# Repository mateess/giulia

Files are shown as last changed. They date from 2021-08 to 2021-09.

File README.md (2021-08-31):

# Giulia
### 40% keyboard project

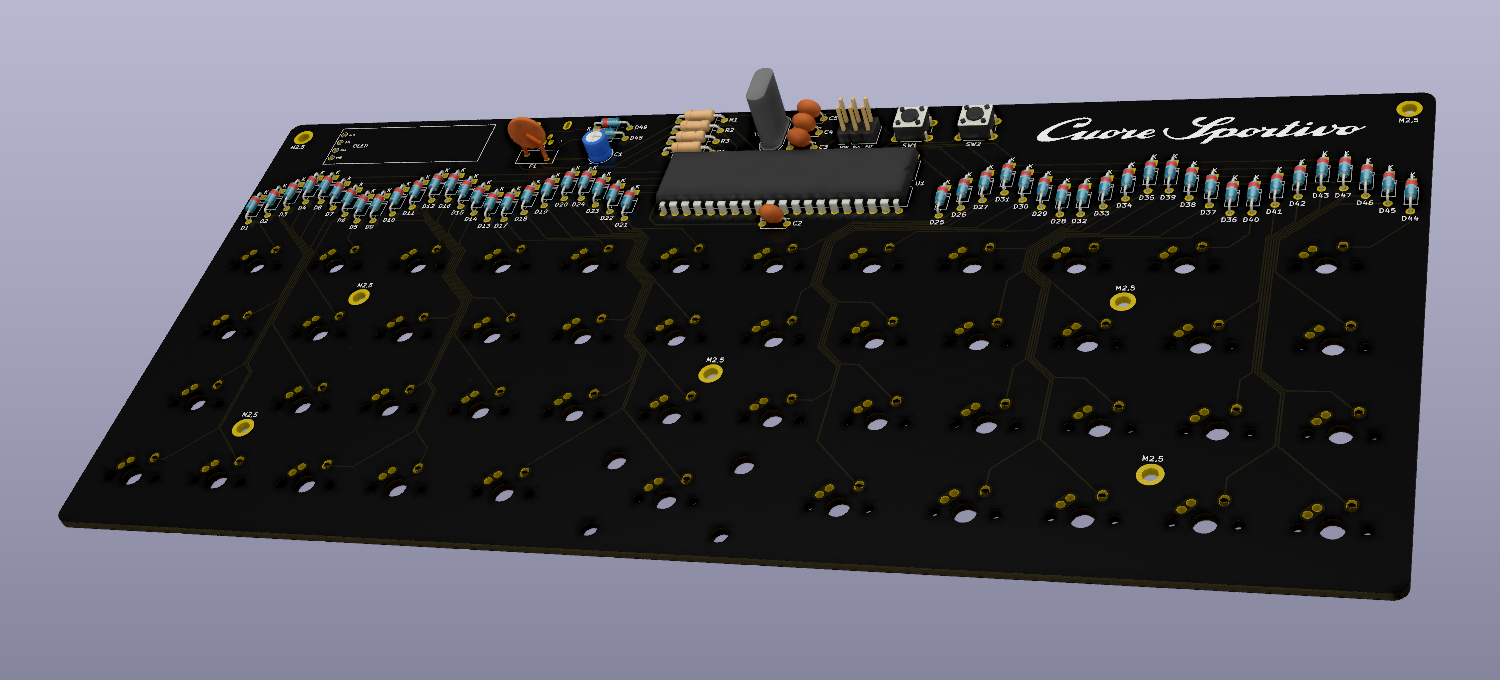
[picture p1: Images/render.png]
render


This will hopefully one day be a complete keyboard.  
Software side is USBaspLoader into QMK  
Inspired by coseyfannitutti's through-hole kits, but with some changes:
- Unistagger layout (like UT47)
- No sandwich, just PCB tray-mounted in a 3D printed lowpro case
- Despite being 40%, uses a "big" ATMega32A controller in DIP
- RGB underglow
- OLED to be admired by non-keeb people and possibly be useful for _stuff_

#### Credit/libraries used:
[Digikey](https://github.com/Digi-Key/digikey-kicad-library) - Molex USB connector  
[foostan](https://github.com/foostan/kbd) - OLED  
[ai03](https://github.com/ai03-2725/MX_Alps_Hybrid) - MX/ALPS switch

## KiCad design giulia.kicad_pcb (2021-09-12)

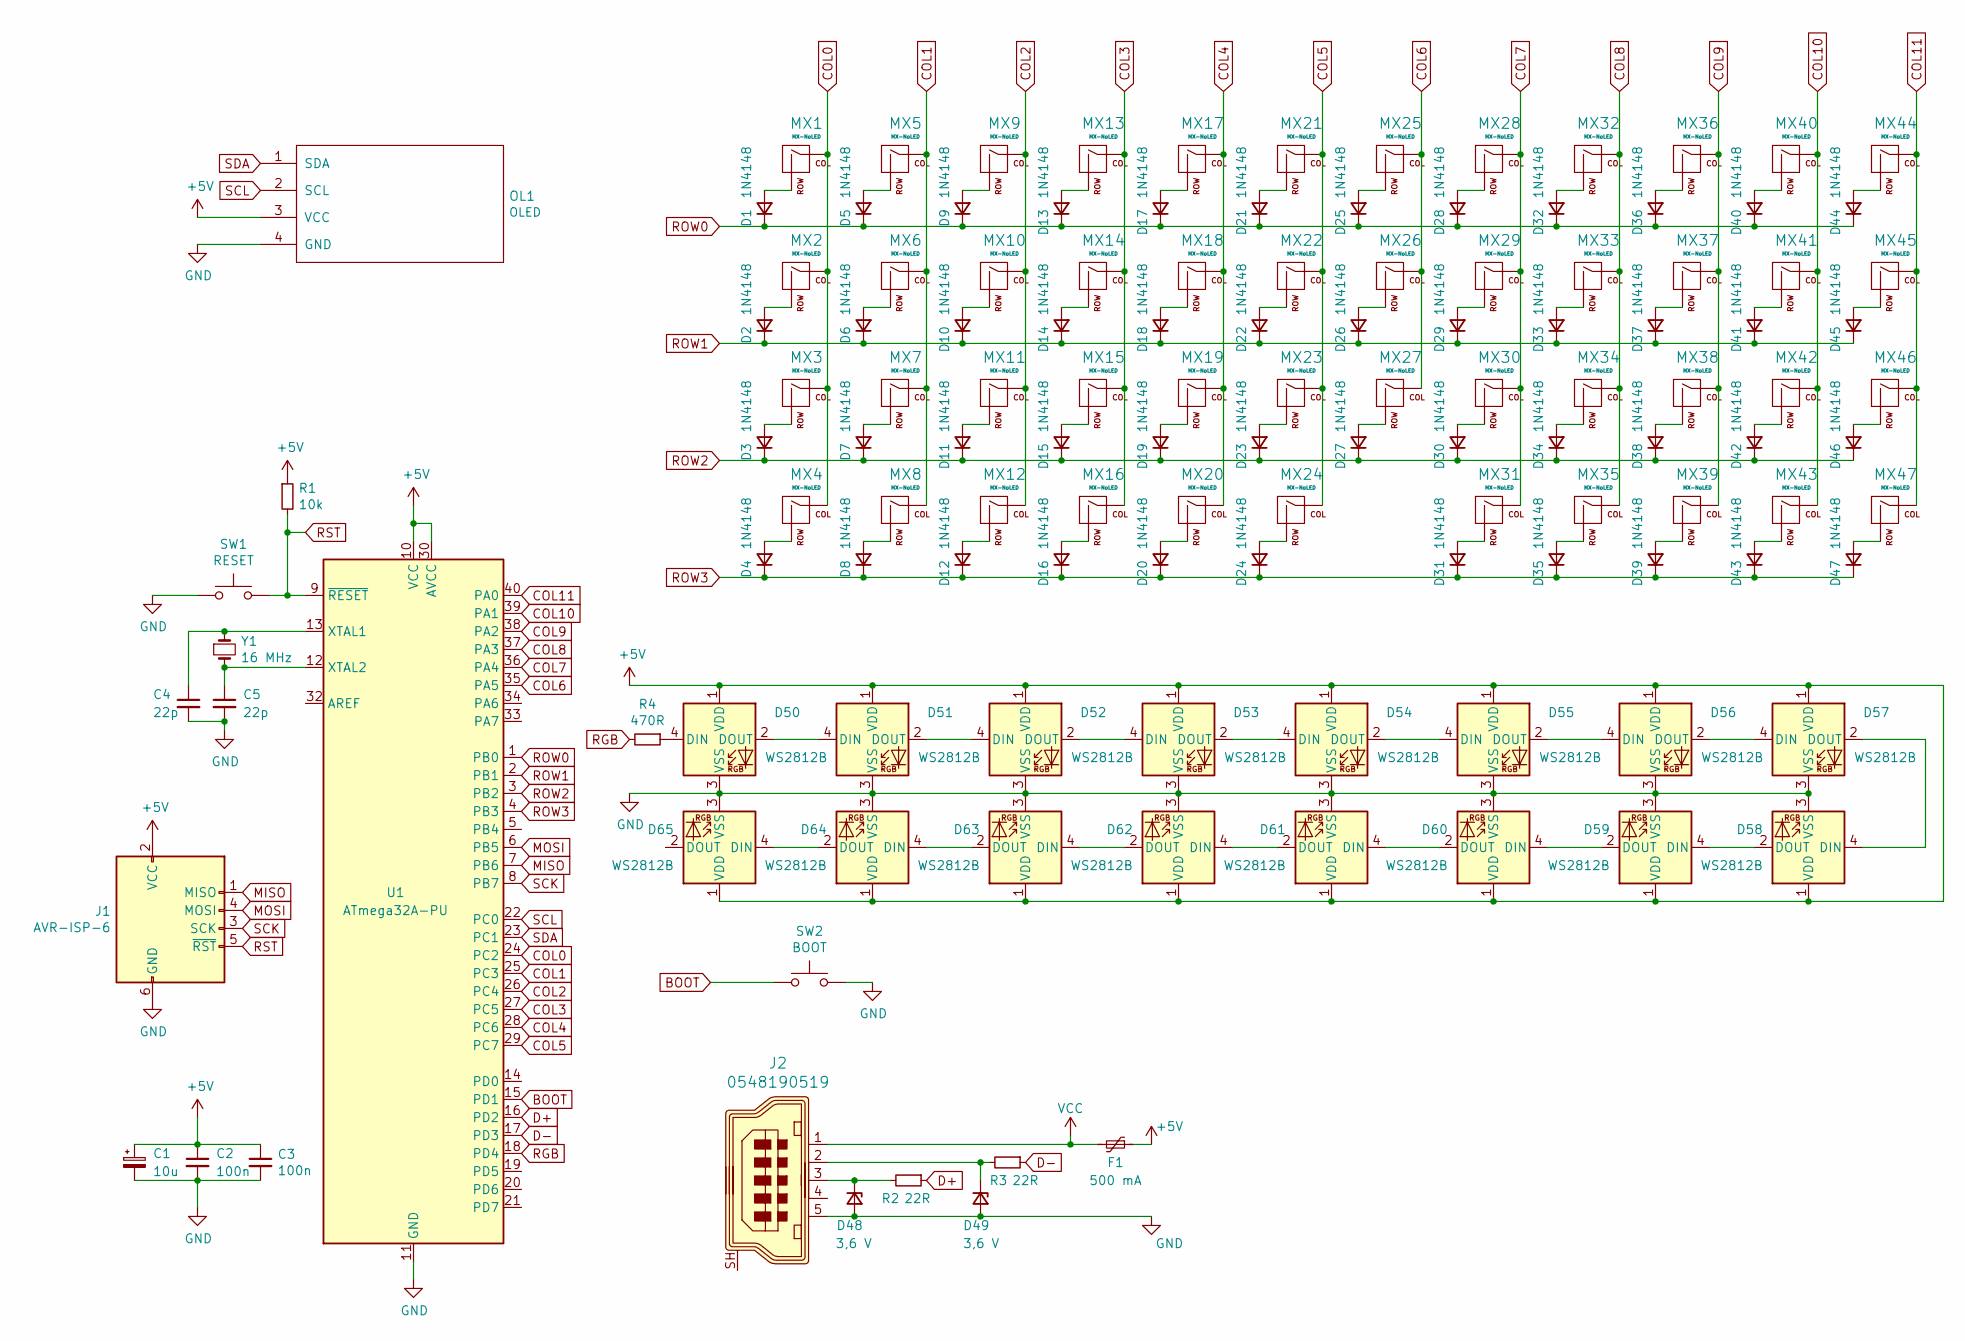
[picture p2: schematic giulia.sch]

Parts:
C1: 10u; CP_Radial_D5.0mm_P2.00mm
C2, C3: 100n; C_Disc_D5.0mm_W2.5mm_P5.00mm
C4, C5: 22p; C_Disc_D5.0mm_W2.5mm_P5.00mm
D1, D2, D3, D4, D5, D6, D7, D8, D9, D10, D11, D12, D13, D14, D15, D16, D17, D18, D19, D20, D21, D22, D23, D24, D25, D26, D27, D28, D29, D30, D31, D32, D33, D34, D35, D36, D37, D38, D39, D40, D41, D42, D43, D44, D45, D46, D47: 1N4148; D_DO-35_SOD27_P7.62mm_Horizontal_Giulia
D48, D49: 3,6 V; D_DO-35_SOD27_P7.62mm_Zener
D50, D51, D52, D53, D54, D55, D56, D57, D58, D59, D60, D61, D62, D63, D64, D65: WS2812B; LED_WS2812B_PLCC4_5.0x5.0mm_P3.2mm
F1: 500 mA; Fuse_BelFuse_0ZRE0005FF_L8.3mm_W3.8mm
J1: AVR-ISP-6; PinHeader_2x03_P2.54mm_Vertical
J2: 0548190519; USB_Mini_B_Female_548190519; MPN 0548190519; Digi-Key_PN WM17115-ND
MX1, MX4, MX5, MX6, MX7, MX8, MX9, MX10, MX11, MX12, MX13, MX14, MX15, MX16, MX17, MX18, MX19, MX21, MX22, MX23, MX25, MX26, MX27, MX28, MX29, MX30, MX32, MX33, MX34, MX35, MX36, MX37, MX38, MX39, MX40, MX41, MX42, MX43, MX46, MX47: MX-NoLED; MX-1U-NoLED
MX2, MX20, MX31, MX45: MX-NoLED; MX-1.25U-NoLED
MX3, MX44: MX-NoLED; MX-1.5U-NoLED
MX24: MX-NoLED; MX-2U-ReversedStabilizers-NoLED
OL1: OLED
R1: 10k; R_Axial_DIN0207_L6.3mm_D2.5mm_P10.16mm_Horizontal
R2, R3: 22R; R_Axial_DIN0207_L6.3mm_D2.5mm_P10.16mm_Horizontal
R4: 470R; R_Axial_DIN0207_L6.3mm_D2.5mm_P10.16mm_Horizontal
SW1: RESET; SW_PUSH_6mm
SW2: BOOT; SW_PUSH_6mm
U1: ATmega32A-PU; DIP-40_W15.24mm
Y1: 16 MHz; Crystal_HC49-U_Vertical

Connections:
+5V: C1.1, C2.1, C3.1, D50.1 (VDD), D51.1 (VDD), D52.1 (VDD), D53.1 (VDD), D54.1 (VDD), D55.1 (VDD), D56.1 (VDD), D57.1 (VDD), D58.1 (VDD), D59.1 (VDD), D60.1 (VDD), D61.1 (VDD), D62.1 (VDD), D63.1 (VDD), D64.1 (VDD), D65.1 (VDD), F1.1, J1.2 (VCC), OL1.3 (VCC), R1.1, U1.10 (VCC), U1.30 (AVCC)
BOOT: SW2.1, U1.15 (PD1)
COL0: MX1.1 (COL), MX2.1 (COL), MX3.1 (COL), MX4.1 (COL), U1.24 (PC2)
COL1: MX5.1 (COL), MX6.1 (COL), MX7.1 (COL), MX8.1 (COL), U1.25 (PC3)
COL2: MX9.1 (COL), MX10.1 (COL), MX11.1 (COL), MX12.1 (COL), U1.26 (PC4)
COL3: MX13.1 (COL), MX14.1 (COL), MX15.1 (COL), MX16.1 (COL), U1.27 (PC5)
COL4: MX17.1 (COL), MX18.1 (COL), MX19.1 (COL), MX20.1 (COL), U1.28 (PC6)
COL5: MX21.1 (COL), MX22.1 (COL), MX23.1 (COL), MX24.1 (COL), U1.29 (PC7)
COL6: MX25.1 (COL), MX26.1 (COL), MX27.1 (COL), U1.35 (PA5)
COL7: MX28.1 (COL), MX29.1 (COL), MX30.1 (COL), MX31.1 (COL), U1.36 (PA4)
COL8: MX32.1 (COL), MX33.1 (COL), MX34.1 (COL), MX35.1 (COL), U1.37 (PA3)
COL9: MX36.1 (COL), MX37.1 (COL), MX38.1 (COL), MX39.1 (COL), U1.38 (PA2)
COL10: MX40.1 (COL), MX41.1 (COL), MX42.1 (COL), MX43.1 (COL), U1.39 (PA1)
COL11: MX44.1 (COL), MX45.1 (COL), MX46.1 (COL), MX47.1 (COL), U1.40 (PA0)
D+: R2.1, U1.16 (PD2)
D-: R3.1, U1.17 (PD3)
GND: C1.2, C2.2, C3.2, C4.2, C5.2, D48.2 (A), D49.2 (A), D50.3 (VSS), D51.3 (VSS), D52.3 (VSS), D53.3 (VSS), D54.3 (VSS), D55.3 (VSS), D56.3 (VSS), D57.3 (VSS), D58.3 (VSS), D59.3 (VSS), D60.3 (VSS), D61.3 (VSS), D62.3 (VSS), D63.3 (VSS), D64.3 (VSS), D65.3 (VSS), J1.6 (GND), J2.5, OL1.4 (GND), SW1.1, SW2.2, U1.11 (GND), U1.31 (GND)
MISO: J1.1 (MISO), U1.7 (PB6)
MOSI: J1.4 (MOSI), U1.6 (PB5)
unnamed: C4.1, U1.13 (XTAL1), Y1.1
unnamed: C5.1, U1.12 (XTAL2), Y1.2
unnamed: D1.2 (A), MX1.2 (ROW)
unnamed: D2.2 (A), MX2.2 (ROW)
unnamed: D3.2 (A), MX3.2 (ROW)
unnamed: D4.2 (A), MX4.2 (ROW)
unnamed: D5.2 (A), MX5.2 (ROW)
unnamed: D6.2 (A), MX6.2 (ROW)
unnamed: D7.2 (A), MX7.2 (ROW)
unnamed: D8.2 (A), MX8.2 (ROW)
unnamed: D9.2 (A), MX9.2 (ROW)
unnamed: D10.2 (A), MX10.2 (ROW)
unnamed: D11.2 (A), MX11.2 (ROW)
unnamed: D12.2 (A), MX12.2 (ROW)
unnamed: D13.2 (A), MX13.2 (ROW)
unnamed: D14.2 (A), MX14.2 (ROW)
unnamed: D15.2 (A), MX15.2 (ROW)
unnamed: D16.2 (A), MX16.2 (ROW)
unnamed: D17.2 (A), MX17.2 (ROW)
unnamed: D18.2 (A), MX18.2 (ROW)
unnamed: D19.2 (A), MX19.2 (ROW)
unnamed: D20.2 (A), MX20.2 (ROW)
unnamed: D21.2 (A), MX21.2 (ROW)
unnamed: D22.2 (A), MX22.2 (ROW)
unnamed: D23.2 (A), MX23.2 (ROW)
unnamed: D24.2 (A), MX24.2 (ROW)
unnamed: D25.2 (A), MX25.2 (ROW)
unnamed: D26.2 (A), MX26.2 (ROW)
unnamed: D27.2 (A), MX27.2 (ROW)
unnamed: D28.2 (A), MX28.2 (ROW)
unnamed: D29.2 (A), MX29.2 (ROW)
unnamed: D30.2 (A), MX30.2 (ROW)
unnamed: D31.2 (A), MX31.2 (ROW)
unnamed: D32.2 (A), MX32.2 (ROW)
unnamed: D33.2 (A), MX33.2 (ROW)
unnamed: D34.2 (A), MX34.2 (ROW)
unnamed: D35.2 (A), MX35.2 (ROW)
unnamed: D36.2 (A), MX36.2 (ROW)
unnamed: D37.2 (A), MX37.2 (ROW)
unnamed: D38.2 (A), MX38.2 (ROW)
unnamed: D39.2 (A), MX39.2 (ROW)
unnamed: D40.2 (A), MX40.2 (ROW)
unnamed: D41.2 (A), MX41.2 (ROW)
unnamed: D42.2 (A), MX42.2 (ROW)
unnamed: D43.2 (A), MX43.2 (ROW)
unnamed: D44.2 (A), MX44.2 (ROW)
unnamed: D45.2 (A), MX45.2 (ROW)
unnamed: D46.2 (A), MX46.2 (ROW)
unnamed: D47.2 (A), MX47.2 (ROW)
unnamed: D48.1 (K), J2.3, R2.2
unnamed: D49.1 (K), J2.2, R3.2
unnamed: D50.2 (DOUT), D51.4 (DIN)
unnamed: D50.4 (DIN), R4.1
unnamed: D51.2 (DOUT), D52.4 (DIN)
unnamed: D52.2 (DOUT), D53.4 (DIN)
unnamed: D53.2 (DOUT), D54.4 (DIN)
unnamed: D54.2 (DOUT), D55.4 (DIN)
unnamed: D55.2 (DOUT), D56.4 (DIN)
unnamed: D56.2 (DOUT), D57.4 (DIN)
unnamed: D57.2 (DOUT), D58.4 (DIN)
unnamed: D58.2 (DOUT), D59.4 (DIN)
unnamed: D59.2 (DOUT), D60.4 (DIN)
unnamed: D60.2 (DOUT), D61.4 (DIN)
unnamed: D61.2 (DOUT), D62.4 (DIN)
unnamed: D62.2 (DOUT), D63.4 (DIN)
unnamed: D63.2 (DOUT), D64.4 (DIN)
unnamed: D64.2 (DOUT), D65.4 (DIN)
RGB: R4.2, U1.18 (PD4)
ROW0: D1.1 (K), D5.1 (K), D9.1 (K), D13.1 (K), D17.1 (K), D21.1 (K), D25.1 (K), D28.1 (K), D32.1 (K), D36.1 (K), D40.1 (K), D44.1 (K), U1.1 (PB0)
ROW1: D2.1 (K), D6.1 (K), D10.1 (K), D14.1 (K), D18.1 (K), D22.1 (K), D26.1 (K), D29.1 (K), D33.1 (K), D37.1 (K), D41.1 (K), D45.1 (K), U1.2 (PB1)
ROW2: D3.1 (K), D7.1 (K), D11.1 (K), D15.1 (K), D19.1 (K), D23.1 (K), D27.1 (K), D30.1 (K), D34.1 (K), D38.1 (K), D42.1 (K), D46.1 (K), U1.3 (PB2)
ROW3: D4.1 (K), D8.1 (K), D12.1 (K), D16.1 (K), D20.1 (K), D24.1 (K), D31.1 (K), D35.1 (K), D39.1 (K), D43.1 (K), D47.1 (K), U1.4 (PB3)
RST: J1.5 (~RST), R1.2, SW1.2, U1.9 (~RESET)
SCK: J1.3 (SCK), U1.8 (PB7)
SCL: OL1.2 (SCL), U1.22 (PC0)
SDA: OL1.1 (SDA), U1.23 (PC1)
VCC: F1.2, J2.1

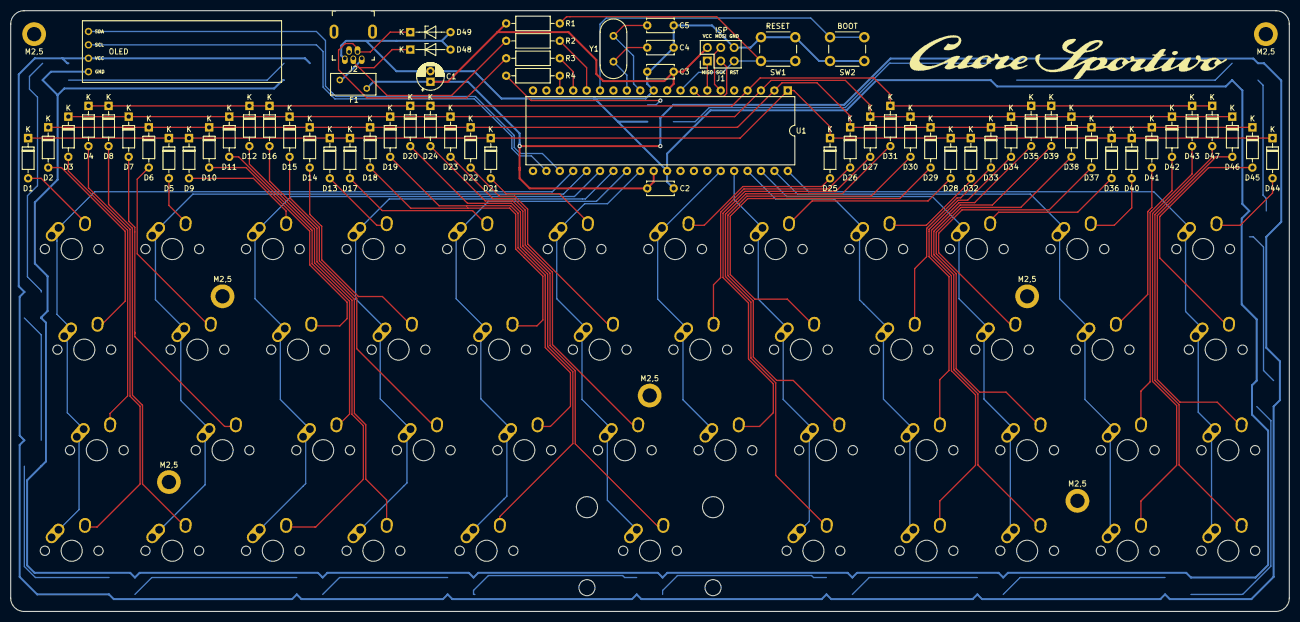
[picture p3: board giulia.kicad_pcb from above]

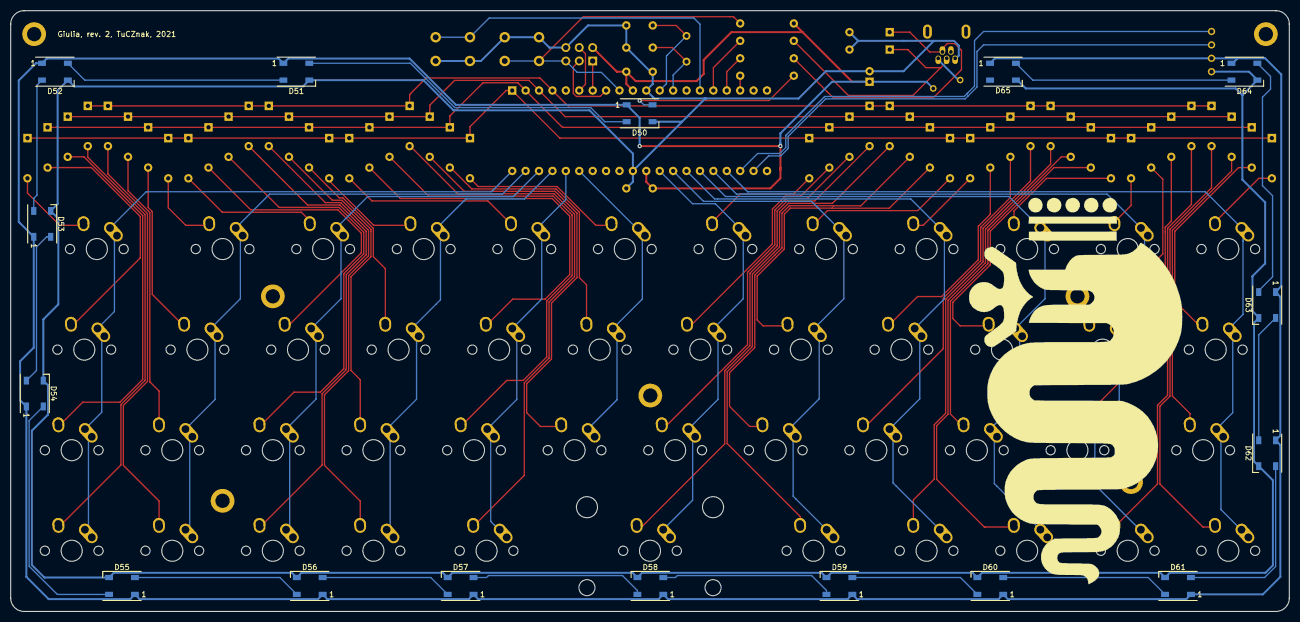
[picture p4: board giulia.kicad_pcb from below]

Board: 2 copper layers, 242.2 x 113.8 mm, 138 parts (16 on the bottom side), 96 nets.

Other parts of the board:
G1: LOGO; Cuore_Sportivo
G2: LOGO; Biscione
M2,5, M2,5#2, M2,5#3, M2,5#4, M2,5#5, M2,5#6, M2,5#7: MountingHole_2.7mm_M2.5_ISO7380_Pad

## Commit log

2021-07-20 Initialize project
    [giulia.kicad_pcb, giulia.sch]
2021-08-01 schematic start
    [giulia.sch]
2021-08-03 basic MCU wiring
    [giulia.sch]
2021-08-08 USB and ISP wiring
    [giulia.sch]
2021-08-08 added matrix
    [giulia.sch]
2021-08-09 minor adjustments
    [giulia.sch]
2021-08-09 schema hopefully complete
    [giulia.sch]
2021-08-09 minor schema stuff
    [giulia.sch]
2021-08-16 added most footprints
    [giulia.sch]
2021-08-16 all footprints assigned
    [giulia.sch]
2021-08-17 adjusted footprints
    changed some footprints based on common parts availability (carbon vs metallic resistors, ceramic condensator pin pitch)
    [giulia.sch]
2021-08-17 Started work on PCB footprints
    [giulia.sch]
2021-08-21 basic component layout
    [giulia.kicad_pcb]
2021-08-25 Adjusting physical component layout
    [giulia.kicad_pcb, giulia.sch]
2021-08-25 PCB progress
    finally placed RGB footprints, added own footprint lib for easy silkscreen adjustment etc.
    [giulia.kicad_pcb, giulia.sch]
2021-08-25 cleaned up libs, removed submodules
    [giulia.kicad_pcb, giulia.sch]
2021-08-25 the madness that is trace routing begins
    [giulia.kicad_pcb]
2021-08-25 top layout that makes more sense
    imagine that, not using 20 vias for basic USB wiring
    [giulia.kicad_pcb]
2021-08-27 routing progress, diode placement change
    [giulia.kicad_pcb]
2021-08-27 switch routing done, fixed MCU position
    [giulia.kicad_pcb]
2021-08-27 rev1 of routing done
    [giulia.kicad_pcb, giulia.sch]
2021-08-27 moved USB footprint to own lib
    [giulia.kicad_pcb, giulia.sch]
2021-08-27 some PCB finishing touches
    [giulia.kicad_pcb, giulia.sch]
2021-08-27 redid column traces
    to be further away from pin support holes (just to be sure)
    also made the PCB a tiny bit larger for underglow trace safety
    [giulia.kicad_pcb]
2021-08-28 rearranged RGB
    [giulia.kicad_pcb]
2021-08-28 minor trace adjustments
    [giulia.kicad_pcb]
2021-08-29 minor tweaks
    [giulia.kicad_pcb]
2021-08-29 moved cols 4,5 to better pins
    [giulia.kicad_pcb, giulia.sch]
2021-08-29 moved resistors for visual alignment
    [giulia.kicad_pcb]
2021-08-29 moved USB data lines
    [giulia.kicad_pcb]
2021-08-29 final PCB rev1
    [giulia.kicad_pcb]
2021-08-29 Gerbers for rev1 generated
    [giulia-B_Cu.gbl, giulia-B_Mask.gbs, giulia-B_SilkS.gbo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]
2021-09-04 Added rev1 of lowpro case
    untested so far
    [Front.stl, Left.stl, Peg.stl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]
2021-09-05 removed case files for now
    thing needs complete redesign on how parts are joined (who would have thought)
    [Front.stl, Left.stl, Peg.stl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]
2021-09-12 fixed USB connector wiring
    The original prototype is wired backwards...
    Also moved boot button from B4 to D1, as having it on different port than USB seems to be giving the bootloader some trouble. This may get reversed if software fix is found.
    [giulia.kicad_pcb, giulia.sch]
2021-09-12 cosmetic adjustments
    since we're changing stuff anyway, might as well fix other minor things
    [giulia.kicad_pcb]
2021-09-12 cosmetic adjustments
    [giulia.kicad_pcb]
